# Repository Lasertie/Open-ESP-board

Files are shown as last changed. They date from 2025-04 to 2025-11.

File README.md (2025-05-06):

# Open ESP Board
# [Le ReadMe est en construction]
## Pourquoi ce projet ?
Le but de cette carte faire un carte ESP32 exclusive pour la domotique. La carte est pensée pou etre "All-proff"
### Histoirex
L' Open ESP Board est né de deux besoins conjoints : Une carte de domotique et une carte multifonction. Mon besoin etait d'avoir une carte domotique current proff, j'avais besoin de pouvoir recevoir un signal éléctique instable et de détecter sa presence. Mais il y avait un autre projet pour Intelli Lab. J'ai donc réunit ces deux besoins pour faire une carte universelle. Malheuresement je n'etait pas expert dans le domaine, mais il me fallait une puce centrale. Donc etant donné la communauté autour de l'ESP32, je me suis tourné vers cette puce.
### La philosophie

## Licence
Ce projet est sous la LOC. Voir [loc.zyglonk.fr](https://loc.zyglonk.fr) pour plus de détails.

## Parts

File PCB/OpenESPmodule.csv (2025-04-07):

Reference | Value | Datasheet | Footprint | Qty | DNP
B1 | BSOURCE | https://ngspice.sourceforge.io/docs/ngspice-html-manual/manual.xhtml |  | 1
C1,C2,C5,C7,C8,C9 | 100n | ~ | Capacitor_SMD:C_0201_0603Metric | 6
C3,C4,C6 | 10u | ~ | Capacitor_SMD:C_0201_0603Metric | 3
D1 | LED |  | LED_THT:LED_VCCLite_5381H5_6.35x6.35mm | 1
D2 | KBPC1510W | https://www.diodemodule.com/bridge-rectifier/kbpc/kbpc1510t.pdf | Diode_THT:Diode_Bridge_GeneSiC_KBPC_W | 1
D3,D4,D5,D6 | D | ~ |  | 4
J1 | PINHD_1x15_Female |  | Connector_PinSocket_2.54mm:PinSocket_1x15_P2.54mm_Vertical | 1
J3 | USB_C_Receptacle_USB2.0_16P | https://www.usb.org/sites/default/files/documents/usb_type-c.zip |  | 1
R1,R2,R4,R5 | 5k1 | ~ | Resistor_SMD:R_0201_0603Metric | 4
R3 | 1k | ~ | Resistor_SMD:R_0201_0603Metric | 1
SW1,SW2 | SW_Push | ~ | Button_Switch_THT:SW_DIP_SPSTx01_Slide_9.78x4.72mm_W7.62mm_P2.54mm | 2
U1 | ESP32-C3-WROOM-02 | https://www.espressif.com/sites/default/files/documentation/esp32-c3-wroom-02_datasheet_en.pdf | RF_Module:ESP32-C3-WROOM-02 | 1
U2 | SPX3819M5-L-3-3 | https://www.exar.com/content/document.ashx?id=22106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 | Package_TO_SOT_SMD:SOT-23-5 | 1
U3 | MCP9700Ax-HLT | http://ww1.microchip.com/downloads/en/devicedoc/20001942g.pdf | Package_TO_SOT_SMD:SOT-353_SC-70-5 | 1
U4 | 4N28 | https://www.vishay.com/docs/83725/4n25.pdf | Package_DIP:DIP-6_W7.62mm | 1

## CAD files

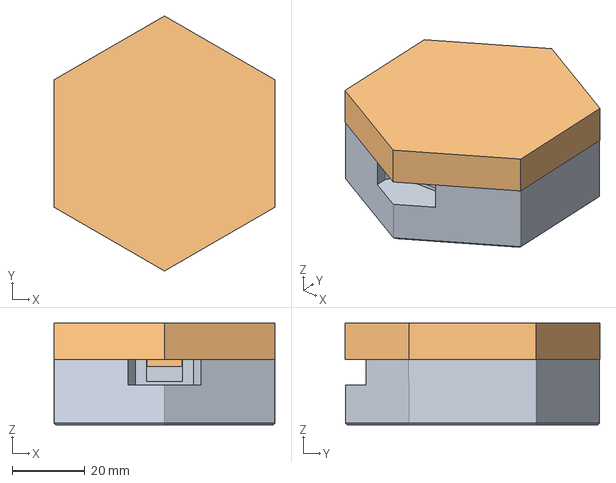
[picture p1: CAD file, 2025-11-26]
Boitier/IL/ILBoxv10.3mf
60.6 x 70.0 x 28.0 mm

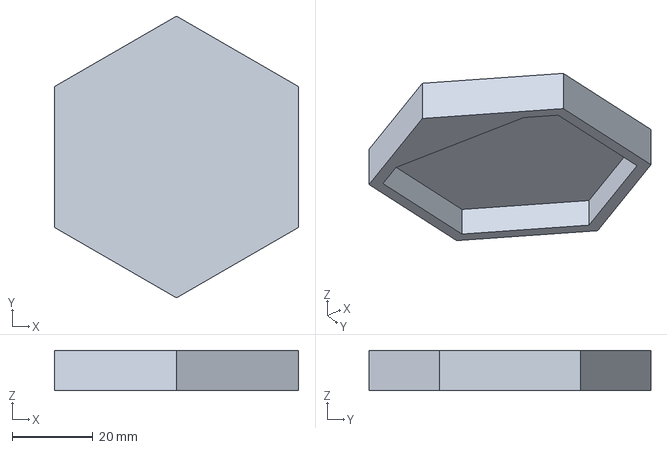
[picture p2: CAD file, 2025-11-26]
Boitier/ILBox-Corps.3mf
60.6 x 70.0 x 10.0 mm

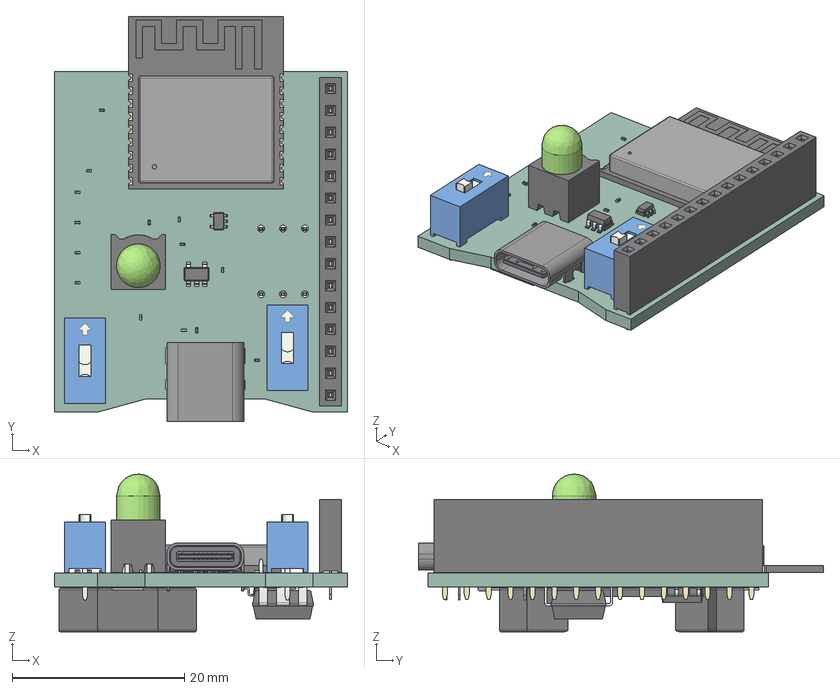
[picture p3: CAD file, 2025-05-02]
PCB/OpenESPmodulev2.step
34.0 x 47.0 x 18.3 mm
R_0201_0603Metric x 5
C_0201_0603Metric x 9
USB_C_Receptacle_GCT_USB4085
Anode_fd_sp
SOT_353_SC_70_5
ESP32-C3-WROOM-02
SW_DIP_SPSTx01_Slide_978x472mm_W762mm_P254mm x 2
PinSocket_1x15_P2.54mm_Vertical
SOT_23_5
SOIC_8_39x49mm_P127mm
Keystone_1060_1x2032
DIP-6_W7.62mm
OpenESPmodule_PCB

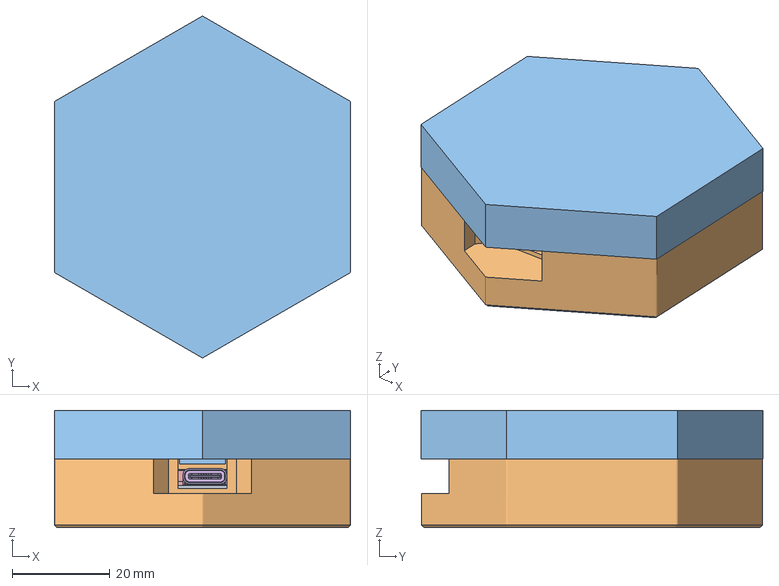
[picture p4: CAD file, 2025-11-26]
Boitier/IL/ILBoxv7ENTIER.3mf
60.6 x 70.0 x 24.0 mm

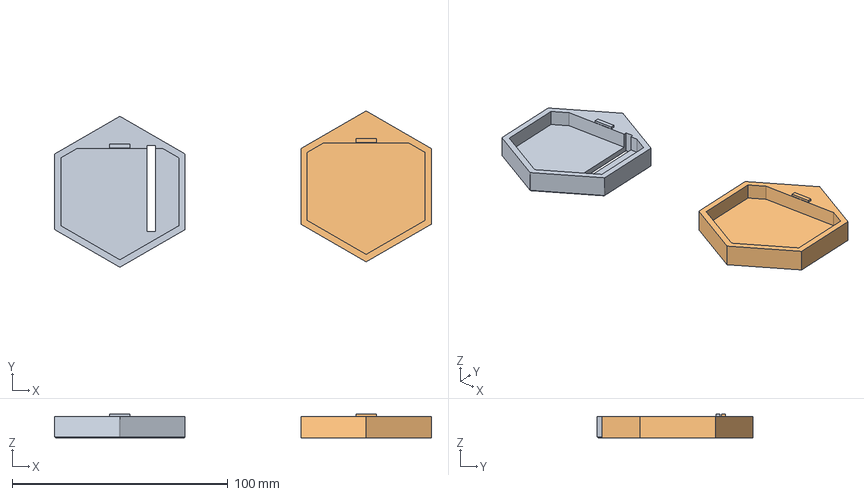
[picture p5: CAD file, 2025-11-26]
Boitier/Open ESP BOX-Corps.3mf
174.8 x 72.4 x 11.0 mm

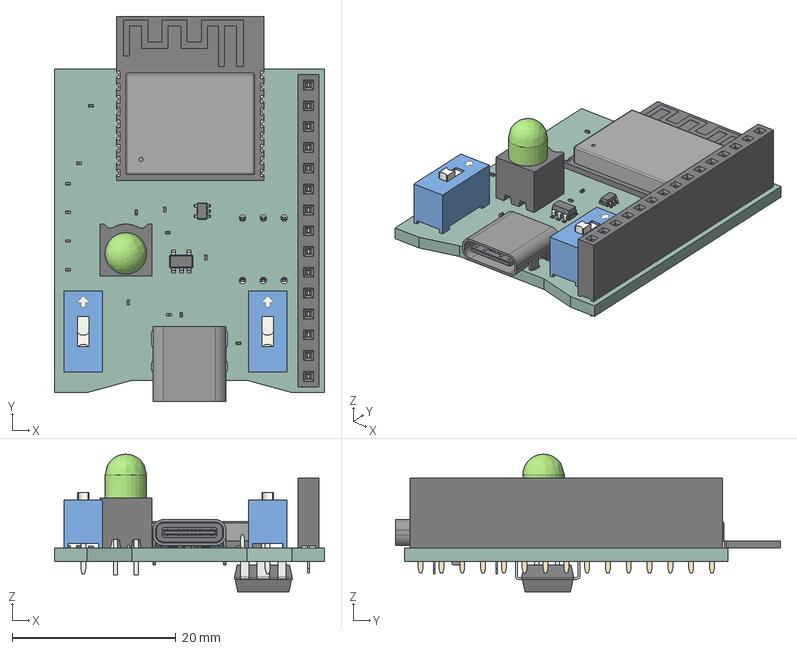
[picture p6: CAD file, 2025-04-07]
PCB/OpenESPmodule.step
33.0 x 47.0 x 16.8 mm
R_0201_0603Metric x 5
C_0201_0603Metric x 9
USB_C_Receptacle_GCT_USB4085
Anode_fd_sp
SOT_353_SC_70_5
ESP32-C3-WROOM-02
SW_DIP_SPSTx01_Slide_978x472mm_W762mm_P254mm x 2
PinSocket_1x15_P2.54mm_Vertical
SOT_23_5
DIP-6_W7.62mm
OpenESPmodule_PCB

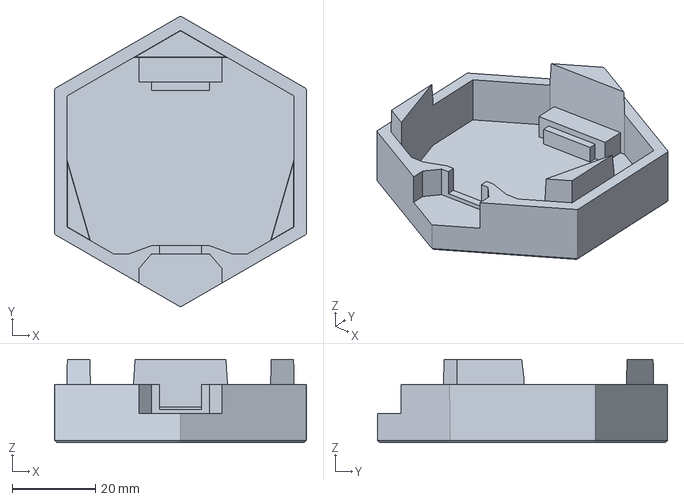
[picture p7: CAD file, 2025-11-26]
Boitier/IL/ILBoxv9Body.3mf
60.6 x 69.8 x 20.0 mm

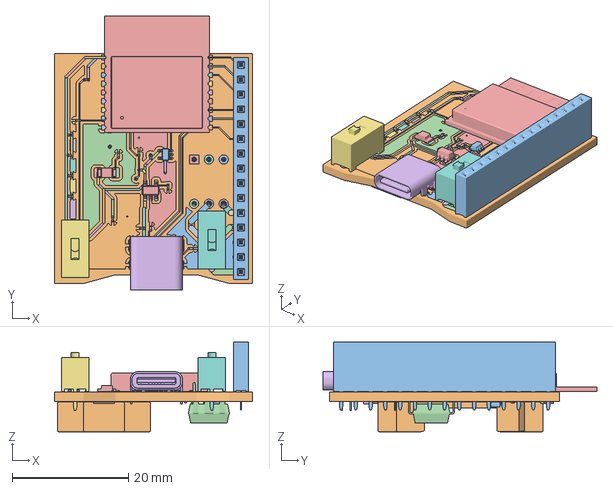
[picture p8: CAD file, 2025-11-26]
Boitier/IL/ILBox-OpenESPmodulev2 1.3mf
34.0 x 47.0 x 15.4 mm

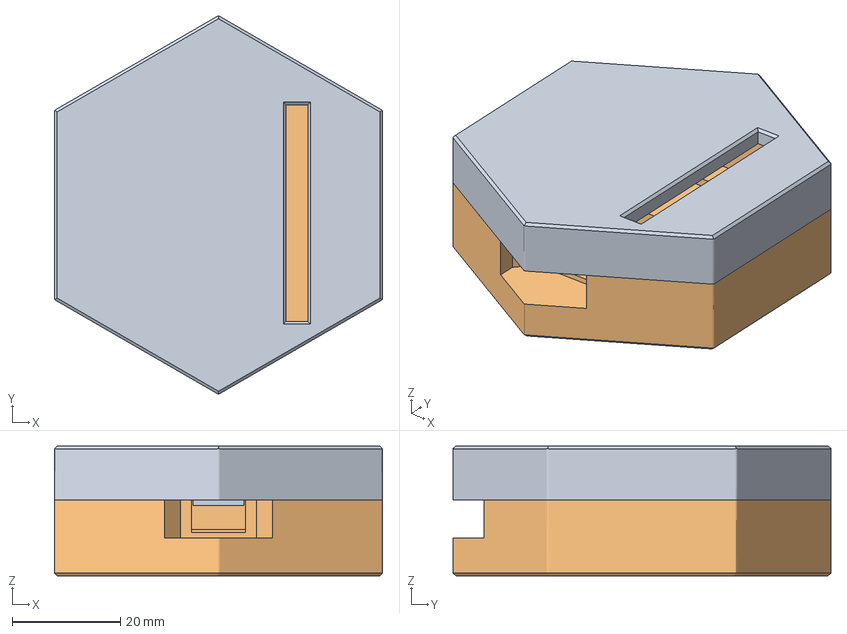
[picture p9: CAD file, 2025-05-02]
Boitier/ILCboxv6.3mf
60.6 x 69.8 x 24.0 mm

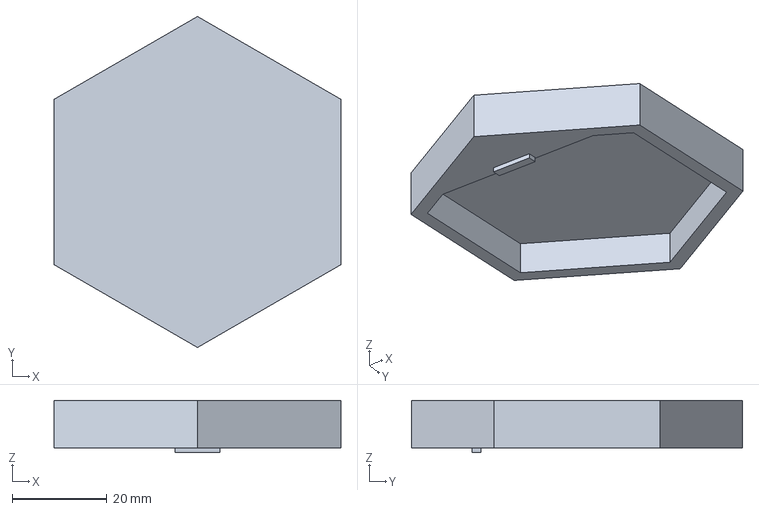
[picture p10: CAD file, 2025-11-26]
Boitier/IL/ILBox-Corps.3mf
60.6 x 70.0 x 11.0 mm

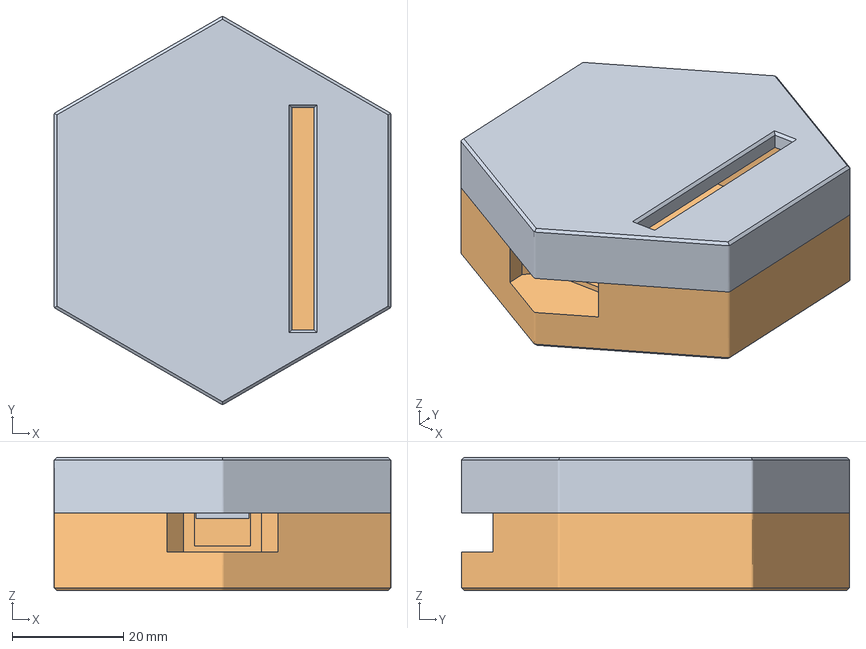
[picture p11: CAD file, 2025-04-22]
Boitier/ILCboxv5.3mf
60.6 x 69.8 x 24.0 mm

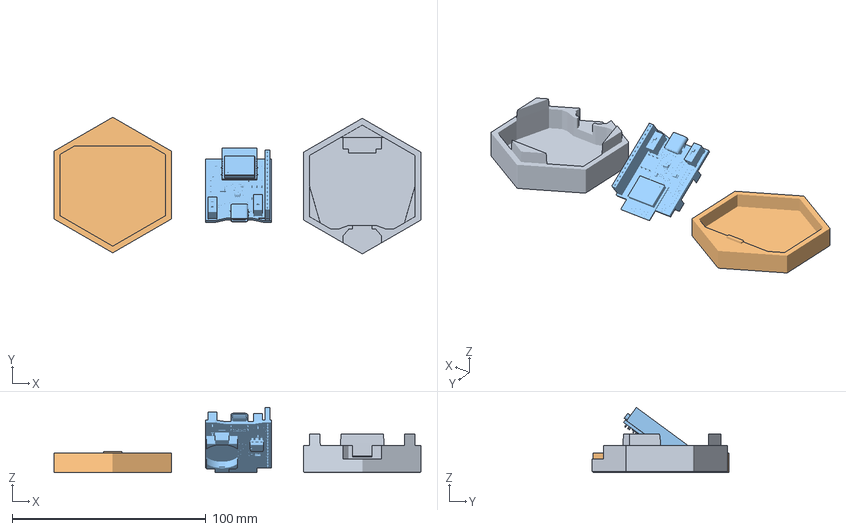
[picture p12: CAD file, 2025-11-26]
Boitier/IL/ILBoxv8ENTIER.3mf
189.4 x 70.5 x 33.6 mm
ILBox-OpenESPmodulev2 1.stl

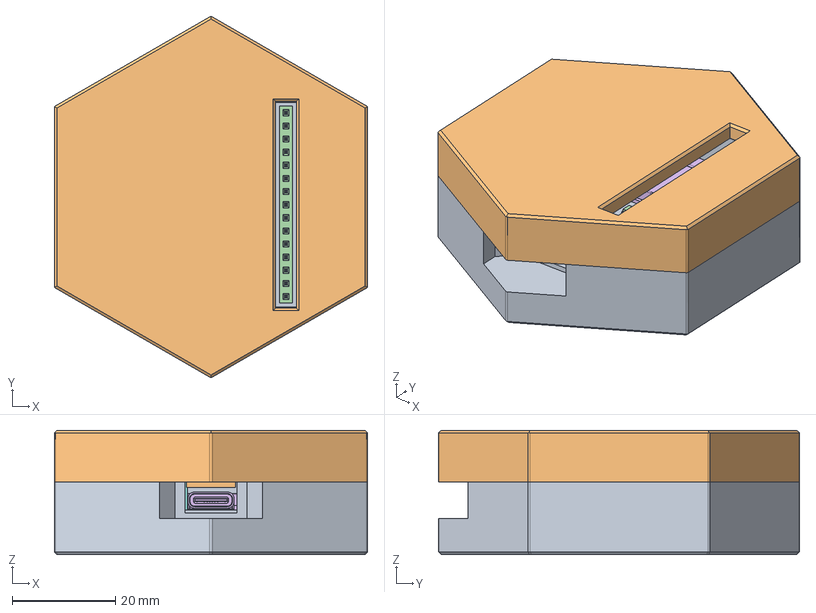
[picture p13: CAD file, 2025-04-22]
Boitier/ILCbox.FCStd
60.6 x 69.8 x 24.0 mm
R_0201_0603Metric
C_0201_0603Metric
R_0201_0603Metric002
R_0201_0603Metric004
USB_C_Receptacle_GCT_USB4085
C_0201_0603Metric002
Anode_fd_sp
C_0201_0603Metric004
R_0201_0603Metric006
C_0201_0603Metric006
SOT_353_SC_70_5
C_0201_0603Metric008
ESP32-C3-WROOM-02
C_0201_0603Metric010
SW_DIP_SPSTx01_Slide_978x472mm_W762mm_P254mm
SW_DIP_SPSTx01_Slide_978x472mm_W762mm_P254mm001
R_0201_0603Metric008
C_0201_0603Metric012
PinSocket_1x15_P2.54mm_Vertical
C_0201_0603Metric014
SOT_23_5
C_0201_0603Metric016
DIP-6_W7.62mm
OpenESPmodule_PCB
Corps

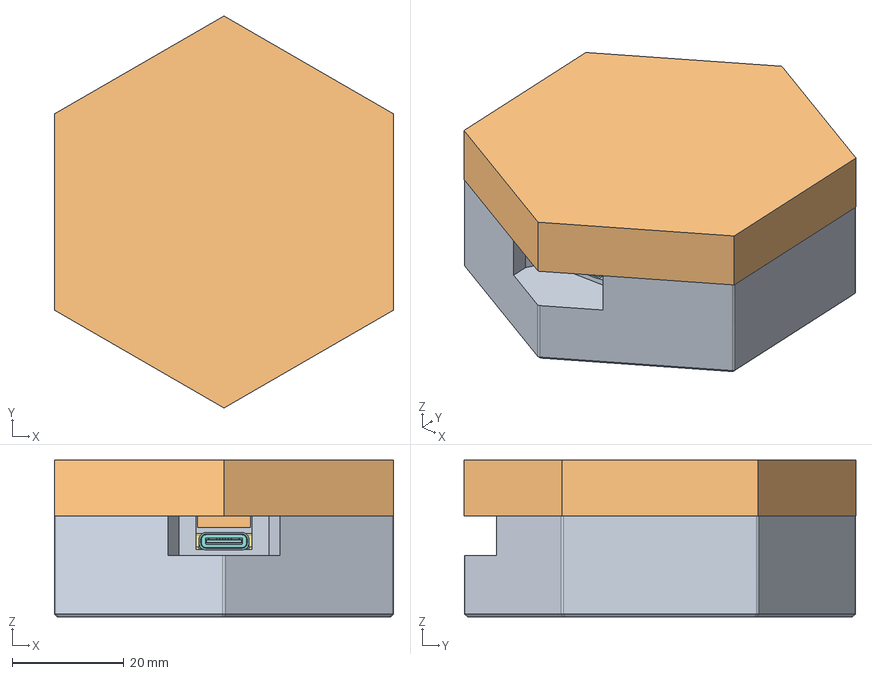
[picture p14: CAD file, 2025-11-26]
Boitier/IL/ILBox.FCStd
60.6 x 70.0 x 28.0 mm
Corps
R_0201_0603Metric010
C_0201_0603Metric018
R_0201_0603Metric012
R_0201_0603Metric014
LED_1206_3216Metric
USB_C_Receptacle_GCT_USB4087
C_0201_0603Metric020
C_0201_0603Metric022
R_0201_0603Metric016
C_0201_0603Metric024
SOT_353_SC_70_006
C_0201_0603Metric026
ESP32-C3-WROOM-004
C_0201_0603Metric028
SW_DIP_SPSTx01_Slide_978x472mm_W762mm_P254mm002
SW_DIP_SPSTx01_Slide_978x472mm_W762mm_P254mm003
R_0201_0603Metric018
C_0201_0603Metric030
C_0201_0603Metric032
SOT_23_006
C_0201_0603Metric034
R_0201_0603Metric020
C_0201_0603Metric036
R_0201_0603Metric022
Keystone_1060_1x2032
TSOT_23_5
DIP-6_W7.62mm002
L_0201_0603Metric
_autosave-OpenESPmodule_track_1
_autosave-OpenESPmodule_track_2
_autosave-OpenESPmodule_track_3
_autosave-OpenESPmodule_track_4
_autosave-OpenESPmodule_track_5
_autosave-OpenESPmodule_track_6
_autosave-OpenESPmodule_track_7
_autosave-OpenESPmodule_track_8
_autosave-OpenESPmodule_track_9
_autosave-OpenESPmodule_track_10
_autosave-OpenESPmodule_track_11
_autosave-OpenESPmodule_track_12
_autosave-OpenESPmodule_track_13
_autosave-OpenESPmodule_track_14
_autosave-OpenESPmodule_track_15
_autosave-OpenESPmodule_track_16
_autosave-OpenESPmodule_track_17
_autosave-OpenESPmodule_track_18
_autosave-OpenESPmodule_track_19
_autosave-OpenESPmodule_track_20
_autosave-OpenESPmodule_track_21
_autosave-OpenESPmodule_track_22
_autosave-OpenESPmodule_track_23
_autosave-OpenESPmodule_track_24
_autosave-OpenESPmodule_track_25
_autosave-OpenESPmodule_track_26
_autosave-OpenESPmodule_track_27
_autosave-OpenESPmodule_track_28
_autosave-OpenESPmodule_track_29
_autosave-OpenESPmodule_track_30
_autosave-OpenESPmodule_track_31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

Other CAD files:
Boitier/Open ESP BOXv7.3mf
Boitier/ILCboxv4.3mf
Boitier/IL/ILBox-OpenESPmodule 1.stl
Boitier/ILCboxv3.3mf
Boitier/IL/ILBox-Bodyv6.stl
Boitier/IL/ILBox-Corps.stl
Boitier/IL/ILBox.stl
Boitier/IL/Radiateur.FCStd
Boitier/ILCbox-bottom.3mf
Boitier/ILCbox.3mf
PCB/OpenESPmodule.3mf
animation.blend

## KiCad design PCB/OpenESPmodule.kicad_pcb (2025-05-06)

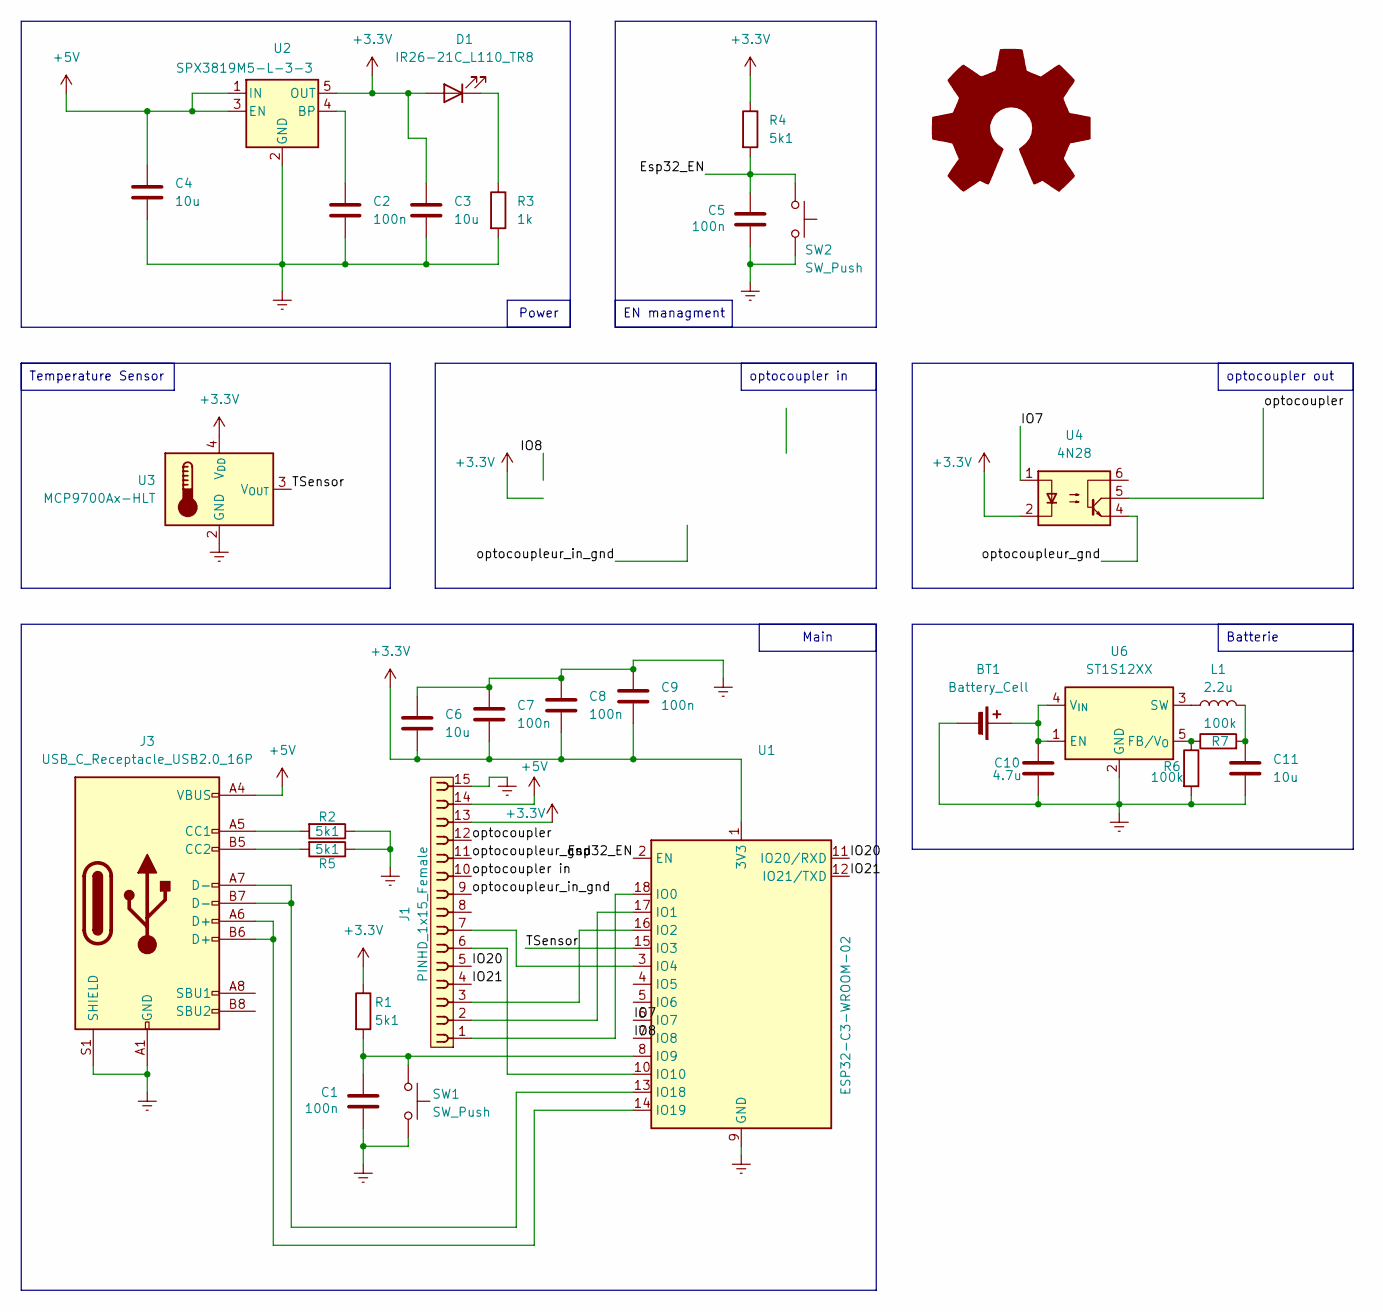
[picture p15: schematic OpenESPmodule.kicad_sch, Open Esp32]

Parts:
BT1: Battery_Cell; BatteryHolder_Keystone_1060_1x2032
C1, C2, C5, C7, C8, C9: 100n; C_0201_0603Metric
C3, C4, C6: 10u; C_0201_0603Metric
C10: 4.7u; C_0201_0603Metric
C11: 10u
D1: IR26-21C_L110_TR8; LED_1206_3216Metric_Pad1.42x1.75mm_HandSolder
J1: PINHD_1x15_Female; PinSocket_1x15_P2.54mm_Vertical
J3: USB_C_Receptacle_USB2.0_16P; USB_C_Receptacle_GCT_USB4085
L1: 2.2u; L_0201_0603Metric
R1, R2, R4, R5: 5k1; R_0201_0603Metric
R3: 1k; R_0201_0603Metric
R6, R7: 100k; R_0201_0603Metric
SW1, SW2: SW_Push; SW_DIP_SPSTx01_Slide_9.78x4.72mm_W7.62mm_P2.54mm
U1: ESP32-C3-WROOM-02
U2: SPX3819M5-L-3-3; SOT-23-5
U3: MCP9700Ax-HLT; SOT-353_SC-70-5
U4: 4N28; DIP-6_W7.62mm
U6: ST1S12XX; TSOT-23-5

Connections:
+3.3V: C3.1, C6.2, C7.2, C8.2, C9.2, D1.2 (A), J1.13, R1.1, R4.1, U1.1 (3V3), U2.5 (OUT), U3.4 (V_{DD}), U4.2
+5V: C4.1, J1.14, J3.A4 (VBUS), J3.A9 (VBUS), J3.B4 (VBUS), J3.B9 (VBUS), U2.1 (IN), U2.3 (EN)
/Esp32_EN: C5.1, R4.2, SW2.1, U1.2 (EN)
/IO7: U1.6 (IO7), U4.1
/IO8: U1.7 (IO8)
/IO20: J1.5, U1.11 (IO20/RXD)
/IO21: J1.4, U1.12 (IO21/TXD)
/TSensor: U1.15 (IO3), U3.3 (V_{OUT})
/optocoupler: J1.12, U4.5
/optocoupler in: J1.10
/optocoupleur_gnd: J1.11, U4.4
/optocoupleur_in_gnd: J1.9
Earth: BT1.2 (-), C1.2, C2.2, C3.2, C4.2, C5.2, C6.1, C7.1, C8.1, C9.1, C10.2, C11.2, J1.15, J3.A1 (GND), J3.A12 (GND), J3.B1 (GND), J3.B12 (GND), J3.S1 (SHIELD), R2.1, R3.2, R5.1, R6.2, SW1.2, SW2.2, U1.9 (GND), U1.19 (GND), U2.2 (GND), U3.2 (GND), U6.2 (GND)
unnamed: BT1.1 (+), C10.1, U6.1 (EN), U6.4 (V_{IN})
unnamed: C11.1, L1.2, R7.2
unnamed: D1.1 (K), R3.1
unnamed: J3.A5 (CC1), R2.2
unnamed: J3.B5 (CC2), R5.2
unnamed: J1.1, U1.18 (IO0)
unnamed: J1.2, U1.17 (IO1)
unnamed: J1.3, U1.16 (IO2)
unnamed: J1.7, U1.3 (IO4)
unnamed: C1.1, R1.2, SW1.1, U1.8 (IO9)
unnamed: J1.6, U1.10 (IO10)
unnamed: J3.A7 (D-), J3.B7 (D-), U1.13 (IO18)
unnamed: J3.A6 (D+), J3.B6 (D+), U1.14 (IO19)
unnamed: C2.1, U2.4 (BP)
unnamed: R6.1, R7.1, U6.5 (FB/V_{O})
unnamed: L1.1, U6.3 (SW)

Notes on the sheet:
Power
Temperature Sensor
EN managment
optocoupler in
Main
optocoupler out
Batterie

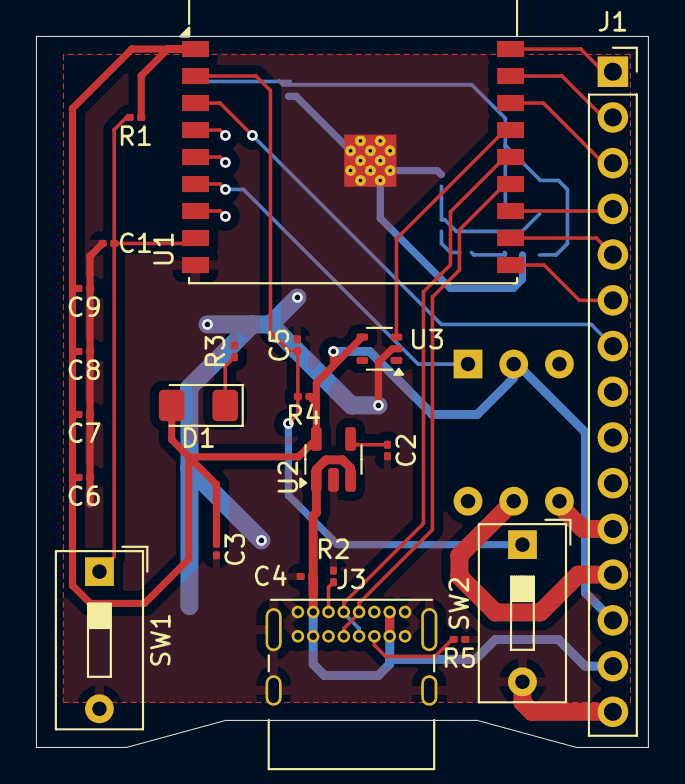
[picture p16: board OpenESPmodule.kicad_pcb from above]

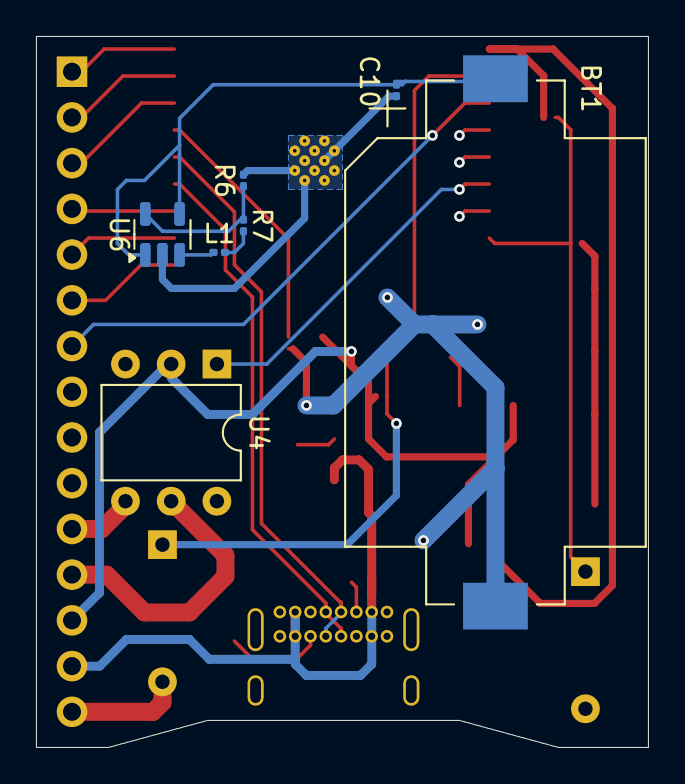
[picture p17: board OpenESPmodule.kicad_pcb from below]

Board: 2 copper layers, 34.0 x 39.5 mm, 29 parts (7 on the bottom side), 26 nets.

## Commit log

2025-04-22 ajout de la fermeture
    [ILBOXTOP.FCStd, ILCbox.FCStd, ILCboxv5.3mf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]
2025-05-02 new box version
    [ILCboxv6.3mf]
2025-05-06 ammelioration de la carte + Update README
    [ILBox-Body.stl, ILBox-Corps.stl, ILBox-OpenESPmodule 1.stl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]
2025-05-06 Add power managment
    [OpenESPmodule.kicad_pcb, OpenESPmodule.kicad_sch]

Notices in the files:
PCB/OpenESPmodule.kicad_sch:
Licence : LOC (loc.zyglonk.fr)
